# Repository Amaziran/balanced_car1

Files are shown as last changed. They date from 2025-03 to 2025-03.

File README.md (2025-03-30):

# balanced_car1
基于STM32的PID平衡小车

该文档中包括了PCB板、STM32CubeMX引脚配置文件以及所有的keil文件，PID算法原理见'PID闭环控制.png',下面说明各部分功能和引脚配置

//OLED:
//	SCL:PB8
//  SDA:PB9

//HC-SR04：
//  Trig:PA11    (GPIO_output)
//	Echo:PB0		 (TIM3输入捕获)

//tb6612
//	PWMA:PA0
//	AIN1:PC14
//	AIN2:PC15
//	STBY:3.3V
//	VM:12V/11.47V
//	VCC:3.3V
//	AO1:M1
//	AO2:M2
//	PWMB:PA3
//	BIN1:PA5
//	BIN2:PA6
//	BO1:M1
//	BO2:M2

//左520电机
//	VCC:3.3V
//	C1:PA9			TIM1 channel2			B相
//	C2:PA8			TIM1 channel1			A相
	
//右电机
//	C1:PB7			TIM4 channel2			B相
//	C2:PB6			TIM4 channel1			A相

//MPU6050
//	SCL:PB4
//	SDA:PB3
//	INT:PB5			EXIT5,触发control

//HC-06蓝牙
//	VCC:3.3
//	单片机TX:PB10  <-->  蓝牙RX
//	单片机RX:PB11  <-->  蓝牙TX
//	获取APP指令的中断在stm32f1xx_it.c文件234行**

调试建议：

这些变量的值会根据小车实际情况进行变化，要想获得较为可靠的平衡需要调节他们：
平衡时角度机械中值Med_Angl；
直立环比例系数Vertical_Kp,积分系数Vertical_Kd；
速度环比例系数Velocity_Kp,微分系数Velocity_Ki；
转向环比例系数Turn_Kp,积分系数Turn_Kd。

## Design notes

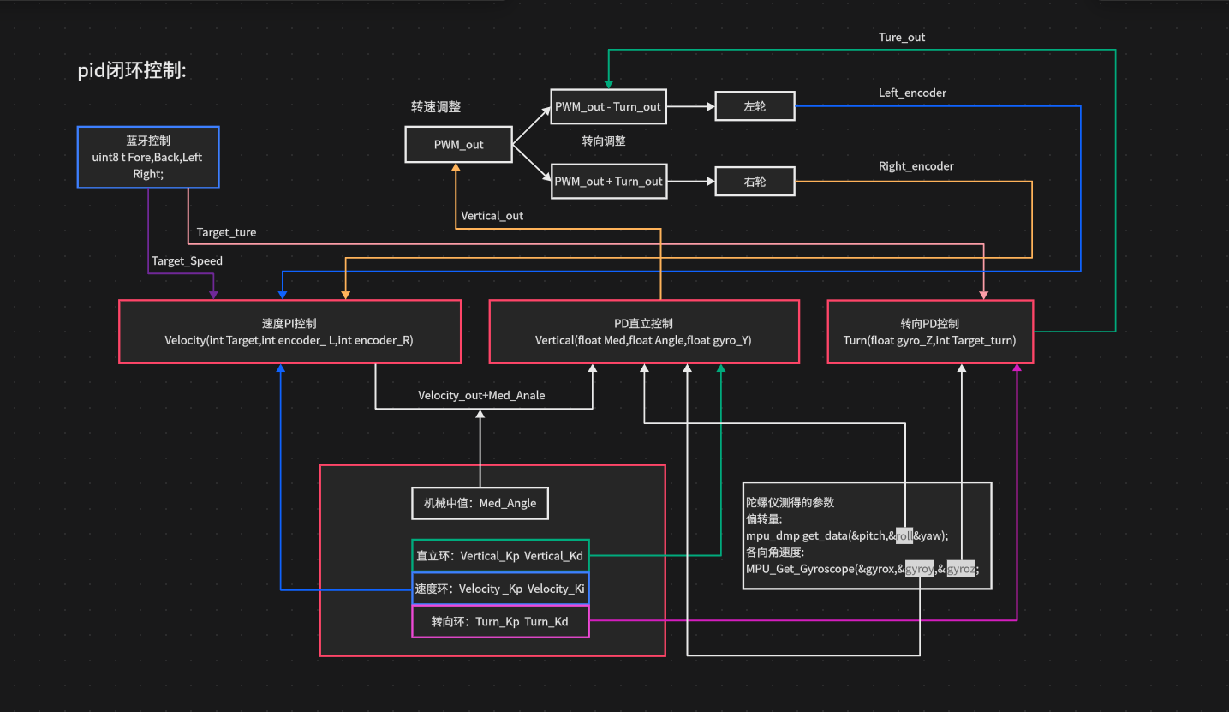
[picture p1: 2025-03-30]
pid闭环控制.png

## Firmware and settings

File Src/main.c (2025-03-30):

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
/* Includes ------------------------------------------------------------------*/
#include "main.h"
#include "i2c.h"
#include "tim.h"
#include "usart.h"
#include "gpio.h"

/* USER CODE BEGIN Includes */
//OLED:
//	SCL:PB8
//  SDA:PB9

//HC-SR04  超声波测距：
//  Trig:PA11    (GPIO_output)
//	Echo:PB0		 (TIM3输入捕获)


//tb6612
//	PWMA:PA0
//	AIN1:PC14
//	AIN2:PC15
//	STBY:3.3V
//	VM:12V/11.47V
//	VCC:3.3V
//	AO1:M1
//	AO2:M2
//	PWMB:PA3
//	BIN1:PA5
//	BIN2:PA6
//	BO1:M1
//	BO2:M2

//左520电机
//	VCC:3.3V
//	C1:PA9			TIM1 channel2			B相
//	C2:PA8			TIM1 channel1			A相
	
//右电机
//	C1:PB7			TIM4 channel2			B相
//	C2:PB6			TIM4 channel1			A相

//MPU6050
//	SCL:PB4
//	SDA:PB3
//	INT:PB5			EXIT5,触发control

//HC-06蓝牙
//	VCC:3.3
//	单片机TX:PB10  <-->  蓝牙RX
//	单片机RX:PB11  <-->  蓝牙TX
//	获取APP指令的中断在stm32f1xx_it.c文件234行


#include "stdio.h"
#include "stdlib.h"
#include "string.h"
#include "oled.h"
#include "tb6612.h"
#include "hc_sr04.h"
#include "IIC.h"
#include "inv_mpu.h"
#include "mpu6050.h"
#include "inv_mpu_dmp_motion_driver.h"
#include "encoder.h"
#include "pid.h"

/* USER CODE END Includes */

/* USER CODE BEGIN PM */
char message[20] = "";

int count = 0;

extern float pitch,roll,yaw;								//陀螺仪三相参数

uint32_t sys_tick = 0;

extern int Encoder_Left,Encoder_Right;

extern double distance;

extern uint8_t rx_buf[2];

/* USER CODE END PM */


void SystemClock_Config(void);
/* USER CODE BEGIN PFP */

void read(void); 

/* USER CODE END PFP */

/**
  * @brief  The application entry point.
  * @retval int
  */
int main(void)
{
  /* MCU Configuration--------------------------------------------------------*/

  /* Reset of all peripherals, Initializes the Flash interface and the Systick. */
  HAL_Init();

  /* Configure the system clock */
  SystemClock_Config();

  /* Initialize all configured peripherals */
  MX_GPIO_Init();
  MX_I2C1_Init();
  MX_TIM3_Init();
  MX_TIM4_Init();
  MX_TIM2_Init();
  MX_TIM1_Init();
  MX_USART3_UART_Init();
  /* USER CODE BEGIN 2 */
	
	
	OLED_Init();
	TB6612_Init();
	MPU_Init();																				//陀螺仪初始化
	mpu_dmp_init();																		//dmp初始化
	Load(0,0);																				//电机初始速度为0
	HAL_TIM_Base_Start(&htim3);												//tim3无更新中断，不加_IT,捕获时钟(hc-sr04)
	//HAL_TIM_Base_Start_IT(&htim3);									//tim3的内部时钟中断，用于测量陀螺仪角度
	HAL_NVIC_SetPriority(EXTI9_5_IRQn, 0, 0);					//设置外部中断优先级
  HAL_NVIC_EnableIRQ(EXTI9_5_IRQn);									//使能外部中断
	HAL_TIM_PWM_Start(&htim2,TIM_CHANNEL_1);					//左电机
	HAL_TIM_PWM_Start(&htim2,TIM_CHANNEL_4);					//右电机
	HAL_TIM_Encoder_Start(&htim1,TIM_CHANNEL_ALL);		//编码器
	HAL_TIM_Encoder_Start(&htim4,TIM_CHANNEL_ALL);		//编码器
	HAL_TIM_IC_Start(&htim3,TIM_CHANNEL_3);						//启动输入捕获的语句，IC：Input Capture
	HAL_TIM_IC_Start_IT(&htim3,TIM_CHANNEL_4);				//在获得两个捕获的值之后需要进行计算，所以需要开一个比较中断，加个_IT
	HAL_UART_Receive_IT(&huart3,rx_buf,1);						
	
	
	OLED_Clear();
	sprintf(message,"Init is OK");
	OLED_ShowString(1,3,(uint8_t *)message,12);
	HAL_Delay(500);
	OLED_Clear();

  /* USER CODE END 2 */

  /* Infinite loop */
  /* USER CODE BEGIN WHILE */
  while (1)
  {
    /* USER CODE END WHILE */

    /* USER CODE BEGIN 3 */
			
//			sprintf(message,"Encoder_L:%d   ",Encoder_Left);
//			OLED_ShowString(1,0,(uint8_t *)message,12);
//			sprintf(message,"Encoder_R:%d   ",Encoder_Right);
//			OLED_ShowString(1,1,(uint8_t *)message,12);
//			sprintf(message,"roll:%.1f   ",roll);
//			OLED_ShowString(1,2,(uint8_t *)message,12);
//			GetDistence();
//			sprintf(message,"dis:%.1fcm  ",distance);
//			OLED_ShowString(1,3,(uint8_t *)message,12);
		
			//一定要尝试加在陀螺仪给的中断里面
			Control();
	
		
			
	}
  /* USER CODE END 3 */
}

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
/* USER CODE BEGIN 4 */

//内部时钟中断回调函数
void HAL_TIM_PeriodElapsedCallback(TIM_HandleTypeDef  *htim)
{
	if(htim == &htim3)
	{
		
	}
}


//
void read(void)
{
	//在系统定义中，uwTick每1ms递增一次
	if(uwTick - sys_tick < 10)							//10ms触发一次
		return ;
	sys_tick = uwTick;
	Encoder_Left = ReadSpeed(&htim1);
	
	Encoder_Right = - ReadSpeed(&htim4);
}
	
	


/* USER CODE END 4 */
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


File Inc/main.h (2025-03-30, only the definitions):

#define AIN1_Pin GPIO_PIN_14
#define AIN1_GPIO_Port GPIOC
#define AIN2_Pin GPIO_PIN_15
#define AIN2_GPIO_Port GPIOC
#define BIN1_Pin GPIO_PIN_5
#define BIN1_GPIO_Port GPIOA
#define BIN2_Pin GPIO_PIN_6
#define BIN2_GPIO_Port GPIOA
#define Trig_Pin GPIO_PIN_11
#define Trig_GPIO_Port GPIOA

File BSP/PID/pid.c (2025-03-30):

#include "pid.h"
#include "encoder.h"
#include "inv_mpu.h"
#include "inv_mpu_dmp_motion_driver.h"
#include "mpu6050.h"
#include "tb6612.h"
#include "stdbool.h"


#define SPEED_Y 30 //俯仰(前后)最大设定速度
#define SPEED_Z 150//偏航(左右)最大设定速度 


//传感器数据变量
int Encoder_Left,Encoder_Right;
float pitch,roll,yaw;
short gyrox,gyroy,gyroz;
short	aacx,aacy,aacz;


//闭环控制中间变量
int Vertical_out,Velocity_out,Turn_out,Target_Speed,Target_turn,MOTO1,MOTO2;
float Med_Angle=3;//平衡时角度值偏移量（机械中值）

//参数
float Vertical_Kp=180,Vertical_Kd=2;			//直立环 数量级（Kp：0~1000、Kd：0~10）
float Velocity_Kp=0.6,Velocity_Ki=0.003;		//速度环 数量级（Kp：0~1）
float Turn_Kp=10,Turn_Kd=0.6;											//转向环

uint8_t stop;

extern TIM_HandleTypeDef htim2,htim4;
extern float distance;
extern uint8_t Fore,Back,Left,Right;										//前后左右为蓝牙APP所传输数据
extern bool distance_warnning;


//直立环PD控制器
//输入：期望角度、真实角度、角速度
int Vertical(float Med,float Angle,float gyro_Y)
{
	int temp;
	//调角度的因数
	temp = 1.25 * Vertical_Kp * (Angle - Med) + Vertical_Kd * gyro_Y;
	return temp;
}


//速度环PI控制器
//输入：期望速度、左编码器、右编码器
int Velocity(int Target,int encoder_L,int encoder_R)
{
	static int Err_LowOut_last,Encoder_S;
	static float a=0.7;
	int Err,Err_LowOut,temp;
	Velocity_Ki = Velocity_Kp / 200;
	//1、计算偏差值
	Err = ( encoder_L + encoder_R ) - Target;
	//2、低通滤波
	Err_LowOut = (1 - a) * Err+a * Err_LowOut_last;
	Err_LowOut_last = Err_LowOut;
	//3、积分
	Encoder_S += Err_LowOut;
	//4、积分限幅(-20000~20000)
	Encoder_S = Encoder_S > 20000 ? 20000:(Encoder_S < (-20000) ? (-20000):Encoder_S);
	if(stop == 1)
		Encoder_S = 0,stop = 0;
	//5、速度环计算
	temp = Velocity_Kp * Err_LowOut + Velocity_Ki * Encoder_S;
	return temp;
}


//转向环PD控制器
//输入：角速度、角度值
int Turn(float gyro_Z,int Target_turn)
{
	int temp;
	temp = Turn_Kp * Target_turn + Turn_Kd * gyro_Z;
	return temp;
}

//PID控制，每隔10ms调用一次
void Control(void)
{
	int PWM_out;
	
	//1、读取编码器和陀螺仪的数据
	Encoder_Left = ReadSpeed(&htim1);										//左
	Encoder_Right= - ReadSpeed(&htim4);									//右
	mpu_dmp_get_data(&pitch,&roll,&yaw);								//陀螺仪偏移量
	MPU_Get_Gyroscope(&gyrox,&gyroy,&gyroz);						//角速度
	MPU_Get_Accelerometer(&aacx,&aacy,&aacz);						//加速度
	
	//蓝牙APP遥控
//	if((Fore == 0) && (Back == 0))											//未接受到前进后退指令-->速度清零，稳在原地
//		Target_Speed=0;
	
	if(Fore == 1)
	{
		Target_Speed = 10;
	}
	
	else if(Back == 1)
	{
		Target_Speed = -10;
	}
	else
	{
		Target_Speed = 0;
	}
	
	//限幅   两个三目运算
	Target_Speed = Target_Speed > SPEED_Y ? SPEED_Y:(Target_Speed < -SPEED_Y ? (-SPEED_Y):Target_Speed);
	
	/*左右*/
	if((Left==0)&&(Right==0))
		Target_turn = 0;
	if(Left==1)
		Target_turn -= 30;	//左转
	if(Right==1)
		Target_turn += 30;	//右转
	
	//限幅( (20*100) * 100   )
	Target_turn = Target_turn > SPEED_Z ? SPEED_Z :(Target_turn < -SPEED_Z ? (-SPEED_Z):Target_turn);
	
	/*转向约束*/
	if((Left==0)&&(Right==0))
		Turn_Kd=0.6;																		//若无左右转向指令，则开启转向约束
	else if((Left==1)||(Right==1))
		Turn_Kd=0;																			//若左右转向指令接收到，则去掉转向约束
	
	
	//2、将数据传入PID控制器，计算输出结果，即左右电机转速值
	//距离小于安全距离时，强制Target_Speed为 -10
	if(distance_warnning == 1)
		Velocity_out = Velocity(-10,Encoder_Left,Encoder_Right);									//仅直立，算出应给角速度
	else
		Velocity_out = Velocity(Target_Speed,Encoder_Left,Encoder_Right);					//在有期望速度的前提下直立，算出应给角速度
	
	//调整roll的角度
	Vertical_out = Vertical(Velocity_out+Med_Angle,roll+7.25,gyrox);				//速度
	Turn_out = Turn(gyroz,Target_turn);																					//偏转
	PWM_out = Vertical_out;
	MOTO1 = PWM_out - Turn_out;
	MOTO2 = PWM_out + Turn_out;
	
	//限幅
	Limit(&MOTO1,&MOTO2);
	//调速
	Load(MOTO1,MOTO2);
}



//可能是触发间隔较短，试试调长点，在MPU_Init函数中
//void HAL_GPIO_EXTI_Callback(uint16_t GPIO_Pin)
//{
//	//PB5接陀螺仪的INT中断
//	if(GPIO_Pin == GPIO_PIN_5)
//			Control();
//	
//}

//void HAL_GPIO_EXTI_Callback(uint16_t GPIO_Pin)
//{
//	if(GPIO_Pin == GPIO_PIN_5)
//	{	Control();
//		HAL_GPIO_WritePin(GPIOB,GPIO_PIN_12,GPIO_PIN_SET);
//	}
//}

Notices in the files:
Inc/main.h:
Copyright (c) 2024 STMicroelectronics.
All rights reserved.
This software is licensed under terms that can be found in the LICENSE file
